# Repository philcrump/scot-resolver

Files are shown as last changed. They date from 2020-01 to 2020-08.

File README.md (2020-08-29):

# scot-resolver

Resolver Interface for the SCOT.

* 22-32V DC Input
* STM32F042K6 Microcontroller @ 48MHz
* MCP2562 CAN 2.0A/B Communication Interface
* AD2S1210 Resolver to Digital Converter
* AD8397 Excitation Driver
* AD8692 Receiver Amplifiers

[**Circuit Board Schematic**](https://github.com/philcrump/scot-resolver/raw/master/scot-resolver-schematic.pdf)

## PCB (CAD Render)

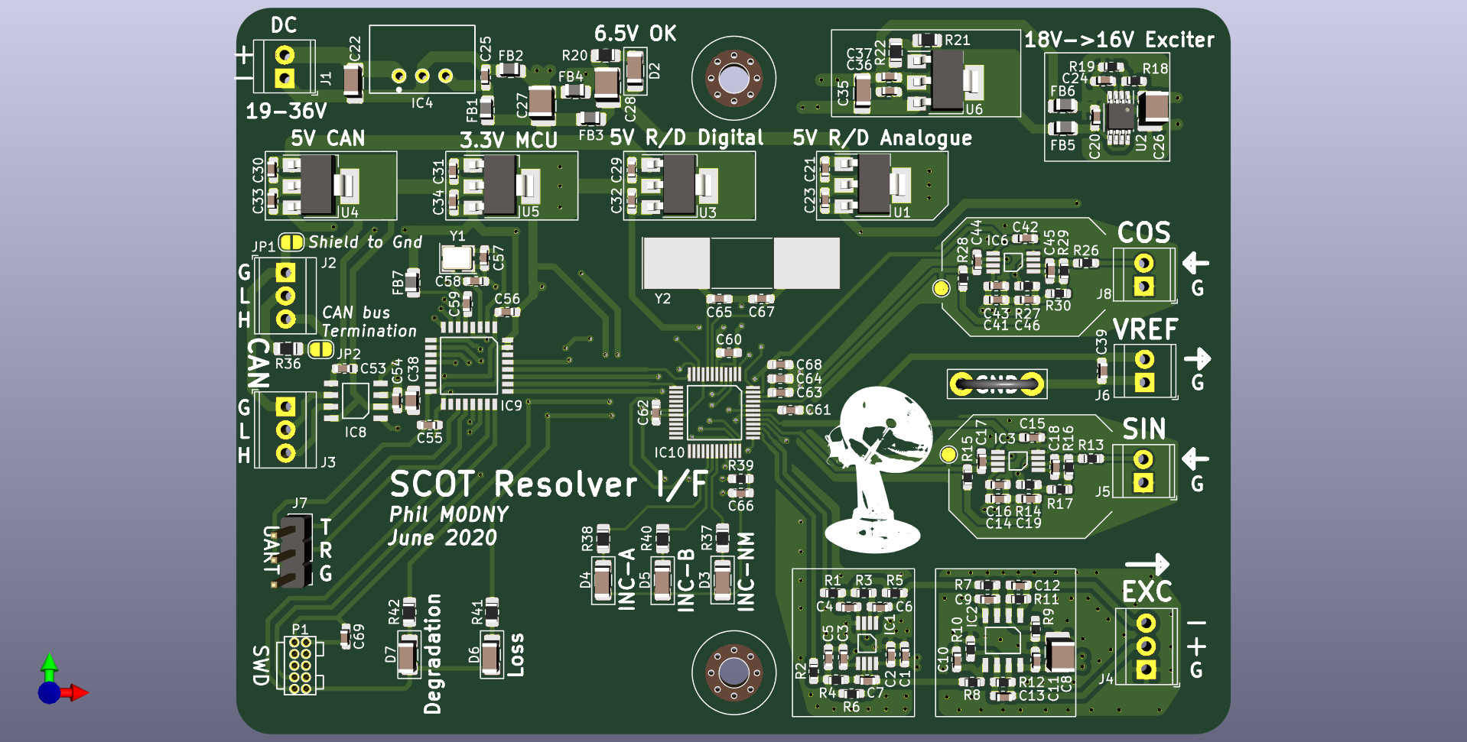
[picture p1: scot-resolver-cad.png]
PCB CAD Render


### June 2020 PCB Errata

* C25 has 0603 pad, C27 & C28 have 1210 pads, all should be 0805 to match the part.
* C26 has 1210 pad, should be 1206.
** Not disastrous, part still fits, with careful placement on 1210 to ensure direct contact with the pads.
* Input Voltage rating is 22-32V, not 19-36V as printed on the PCB (limited by U6-LM317 dropout and thermal).
* Optional Ripple Rejection Capacitor should be fitted across R22 (LM317 regulator)
** 2u2 50V found to prevent oscillation with hostile downstream load (oscillating U2-LT1763)
* C24 U2-LT1763 Bypass Capacitor is incorrectly placed, causes self-oscillation, and should not be populated.
** Attempt to wire this across to Vout instead as recommended also caused output oscillation when under load (25mA).
* U6-LM317 regulator gets hot, within limits but would benefit from more heatsinking / different package.

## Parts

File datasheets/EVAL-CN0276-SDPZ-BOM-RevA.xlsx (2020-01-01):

Title: | CN0276 Bill of Materials
Rev: | 0
Date: | 07/10/2013
Quantity | Reference Designator(s) | Value | Package | Manufacturer | Manufacturer Part Number | Nashua Part Number
2 | C1-2 | 33p | 2012 | KEMET | C0805C330J5GACTU | 7000831
4 | C3-4 C16-17 | 3.9n | 2012 | KOA | NPO0805HTTD3R9J | 7000222
4 | C5-6 C12-13 | 120p | 2012 | muRata | GRM2165C2A121JA01 | .
4 | C7-8 C14-15 | 680p | 2012 | AVX | 08055A681FAT2A | 7000186
1 | C10 | 10n | 2012 | AVX | 08051C103KAT2A | 7000032
6 | C11 C35 C40 C50 C52 C54 | 10u | 2012 | TDK | C2012X5R1V106M125AC | .
2 | C18 C32 | 470p | 2012 | muRata | GRM2165C2A471JA01 | .
2 | C21 C26 | 2.7n | 2012 | TDK | C2012C0G1H272J060AA | .
16 | C22-24 C30-31 C34 C36-37 C39 C41-42 C44-46 C51 C9 | 100n | 2012 | Yageo | CC0805KRX7R8BB104 | 7000758
1 | C38 | 100u | 7343 | AVX | TAJE107M025RNJ | .
2 | C25 C28 | 470u | 7343 | VISHAY | TR3D477M6R3C0200 | 7001327
2 | C20 C29 | 56p | 2012 | muRata | GRM21A5C2E560JW01D | .
2 | C33 C19 | 2.2n | 2012 | TDK | C2012C0G1H222J085AA | .
6 | C43 C27 C47-49 C53 | 1u | 2012 | AVX | 0805ZC105KAT2A | 7000264
2 | D1-2 |  | 2012 | Lumex | SML-LXT0805GW-TR | 7001182
1 | D3 |  | 2012 | Kingbright | APT2012QBC/D | .
1 | D4 |  | 2012 | Kingbright | APT2012SYCK | .
2 | D5-6 |  | 2012 | Avago | HSMS-C170 | 7001059
1 | J1 |  | FX8-120S-SV | HIROSE | FX8-120S-SV | 6000923
1 | J2 |  | IDC20 | Tyco Electronics | 2-1634688-0 | .
1 | J3 |  | 2510-6PIN | Tyco Electronics | 640456-6 | .
1 | J4 |  | 301-2PIN | Weidmüller | PM 5.08/02/90 | 6001003
1 | L1 | 1k | 2012 | TDK | MMZ2012R102A | .
4 | R1 R11 R24 R33 | 4.7k | 2012 | KOA | RK73B2ATTDD472J | 7000044
8 | R5 R2-3 R25-28 R4 | 27k | 2012 | VISHAY | CRCW080527K0FK | .
5 | R7 R6 R16 R47 R57 | 10k | 2012 | KOA | RK73B2ATTD103J | 7000039
1 | R13 | NP
4 | R14-15 R29 R32 | 2k | 2012 | VISHAY | CRCW08052K00FK | 7001433
4 | R30-31 R17-18 | 1.2k | 2012 | KOA | RK73B2ATTDD122J | 7000249
1 | R19 | 100k | 2012 | VISHAY | CRCW0805100KFK | .
5 | R20 R23 R12 R10 R58 | 0 | 2012 | Panasonic | ERJ-6GEY0R00V | 7000228
4 | R8-9 R21-22 | 22k | 2012 | KOA | RK73B2ATTDD223J | 7000095
6 | R34-39 | 1k | 2012 | Yageo | RC0805JR-071KL | 7000554
2 | R40 R56 | 3.3k | 2012 | VISHAY | CRCW08053K30FK | .
2 | R41 R54 | 750 | 2012 | KOA | RK73B2ATTDD751J | 7000162
2 | R43 R52 | 6.2k | 2012 | VISHAY | CRCW08056K20FK | .
2 | R45 R51 | 910 | 2012 | VISHAY | CRCW0805910RFK | .
2 | R46 R48 | 820 | 2012 | VISHAY | CRCW0805820RFK | .
1 | R49 | 390 | 2012 | VISHAY | CRCW0805390RFK | .
4 | R50 R44 R53 R42 | 20k | 2012 | VISHAY | CRCW080520K0FK | .
1 | R55 | 1.6k | 2012 | VISHAY | CRCW08051K60FK | .
1 | U1 |  | SOIC-8 | Microchip | 24LC32A-I/SN | 1000614
2 | U2 U5 |  | SOIC-14 | Analog Devices, Inc. | AD8694ARZ | .
1 | U3 |  | TSSOP-16 | Analog Devices, Inc. | ADG1611BRUZ | .
1 | U4 |  | LQFP-48 | Analog Devices, Inc. | AD2S1210BSTZ | .
1 | U6 |  | SOIC-8 | Analog Devices, Inc. | AD8692ARZ | .
1 | U7 |  | SOIC-EP-8 | Analog Devices, Inc. | AD8397ARDZ | 30-025792-01
1 | U8 |  | TSSOP-16 | Analog Devices, Inc. | ADG1612BRUZ | .
1 | U9 |  | SOT-23-3 | Analog Devices, Inc. | ADM6328-22ARTZ-R7 | .
1 | U10 |  | SOIC-EP-8 | Analog Devices, Inc. | ADP7104ARDZ-5.0-R7 | 30-026221-01
1 | U11 |  | SOIC-EP-8 | Analog Devices, Inc. | ADP7104ARDZ-3.3-R7 | 30-026222-01
1 | U12 |  | SOT-23-3 | VISHAY | SI2343CDS | 1000351
1 | Y1 | 8.192M | HCM49 | TXC | 9C-8.192MAAJ-T | .

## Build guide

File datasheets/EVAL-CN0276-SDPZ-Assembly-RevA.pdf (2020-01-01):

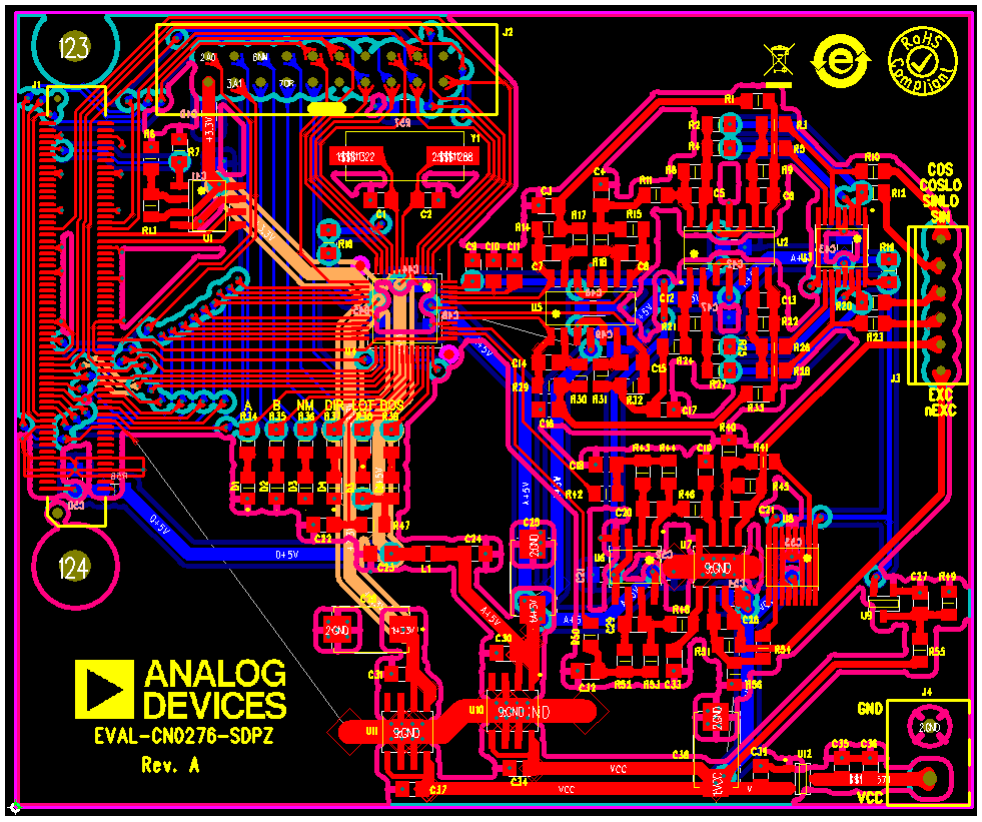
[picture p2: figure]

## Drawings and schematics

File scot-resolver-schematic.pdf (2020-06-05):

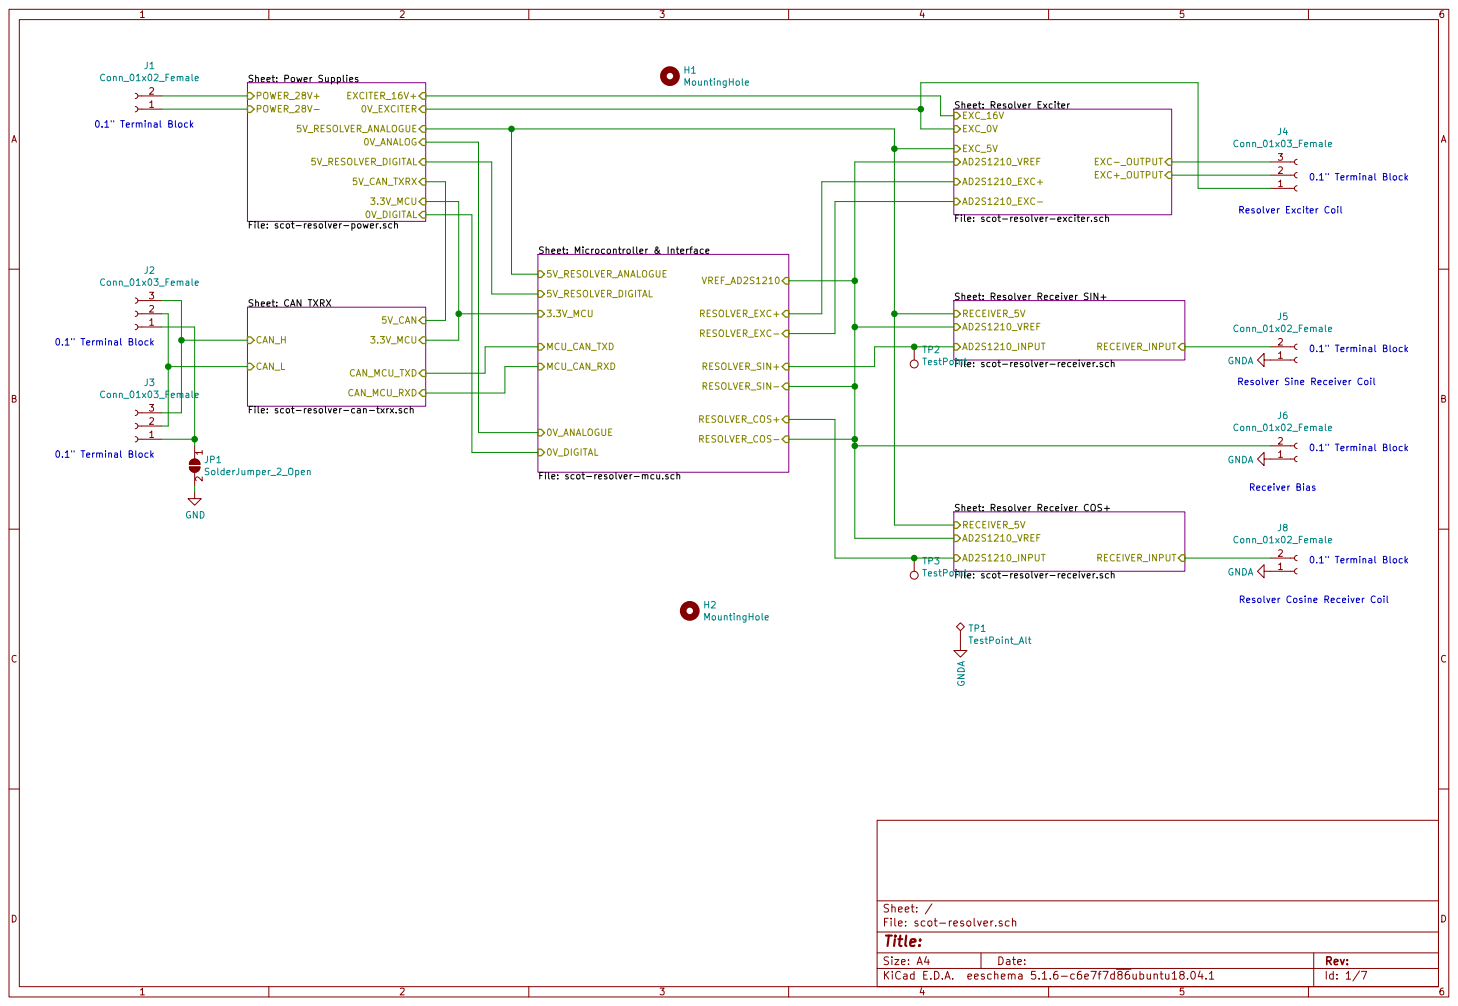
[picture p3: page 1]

Sheet: Microcontroller & Interface File: scot-resolver-mcu.sch MCU_CAN_TXD MCU_CAN_RXD

File: scot-resolver-can-txrx.sch CAN_L CAN_H

Id: 1/7 Title: File: scot-resolver.sch Sheet: /

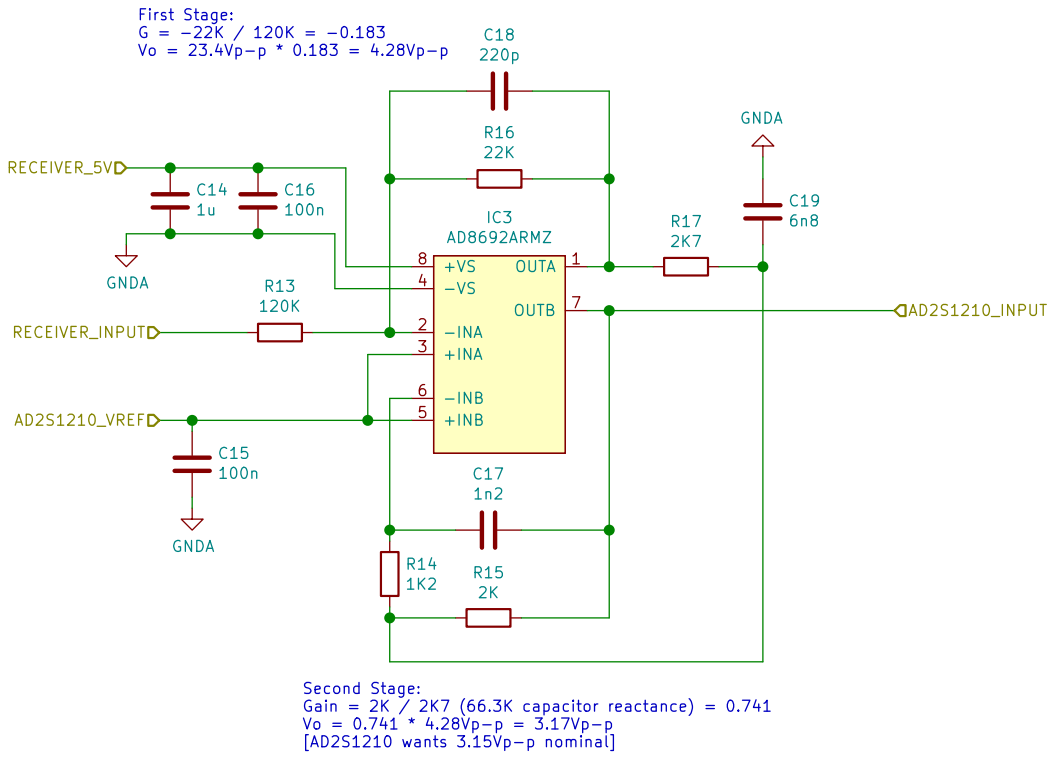
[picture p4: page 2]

Id: 2/7 Title: File: scot-resolver-receiver.sch Sheet: /Resolver Receiver SIN+/

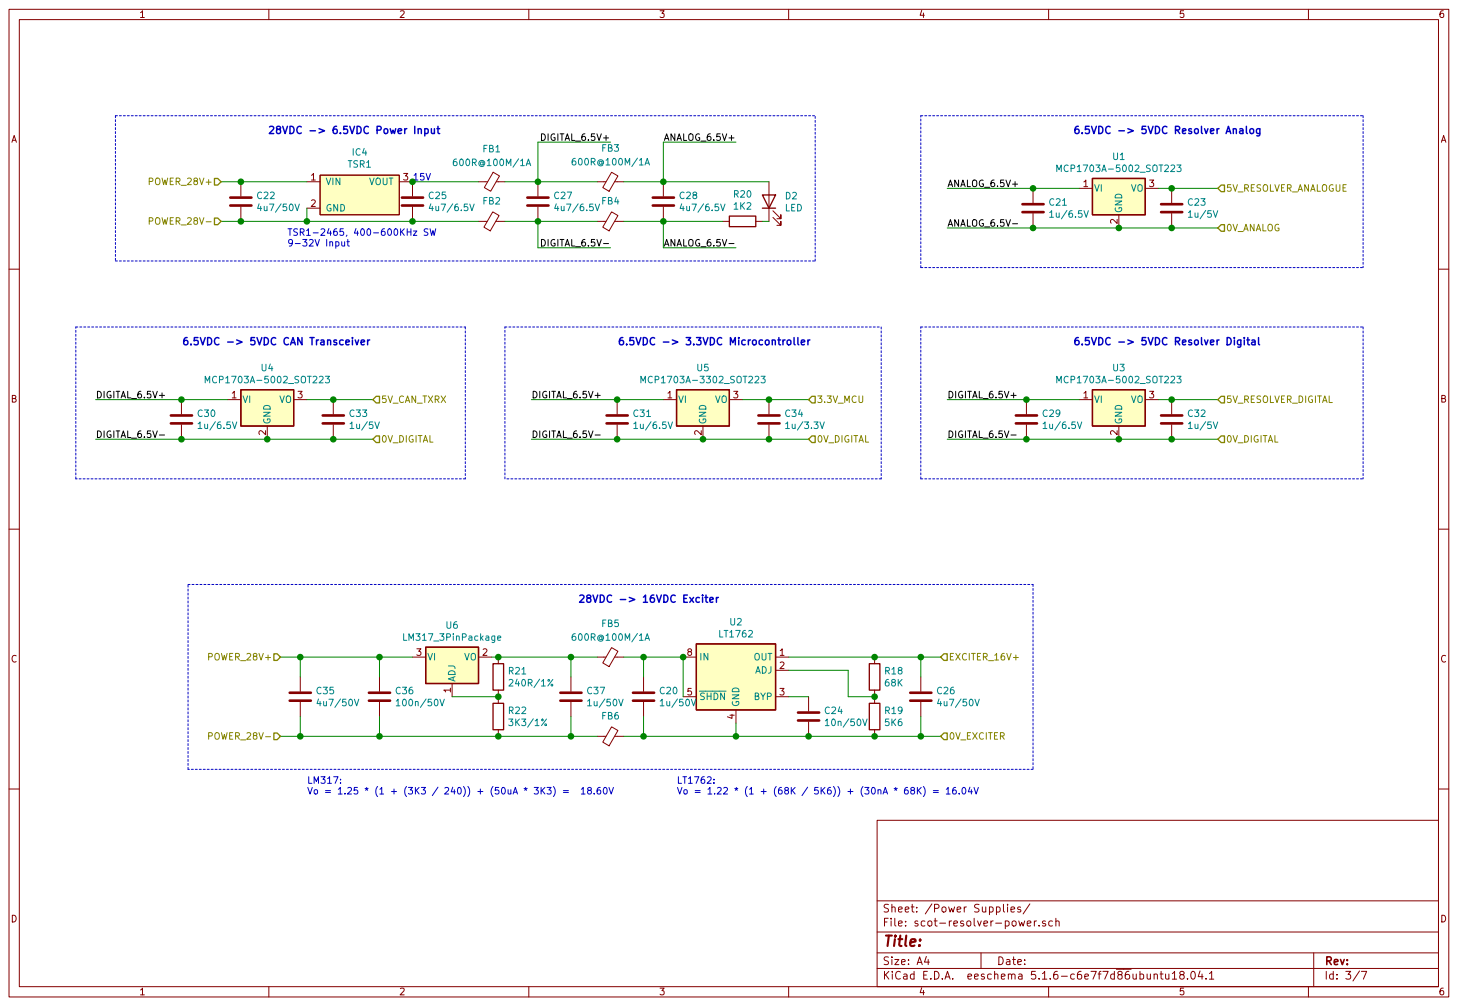
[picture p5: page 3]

Sheet: /Power Supplies/
File: scot-resolver-power.sch
Id: 3/7 Title:

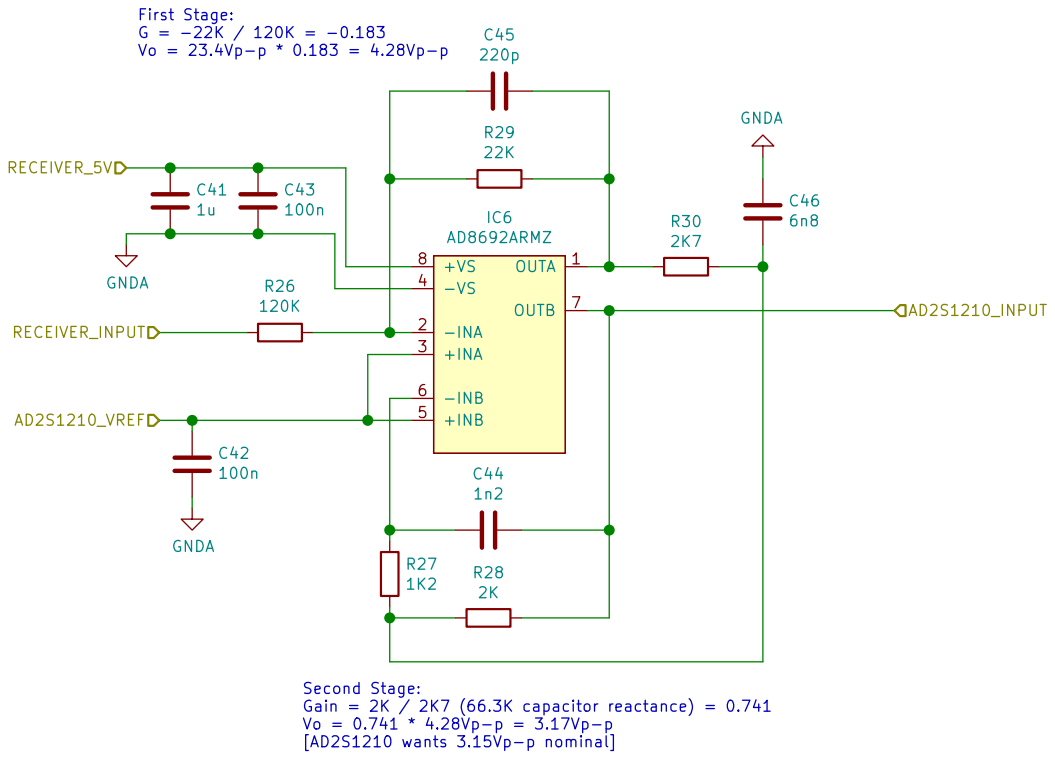
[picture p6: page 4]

Id: 4/7 Title: File: scot-resolver-receiver.sch Sheet: /Resolver Receiver COS+/

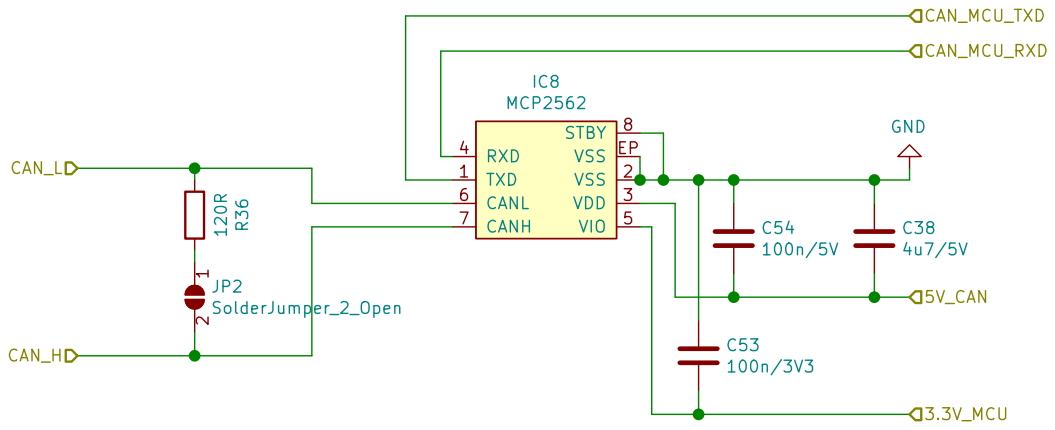
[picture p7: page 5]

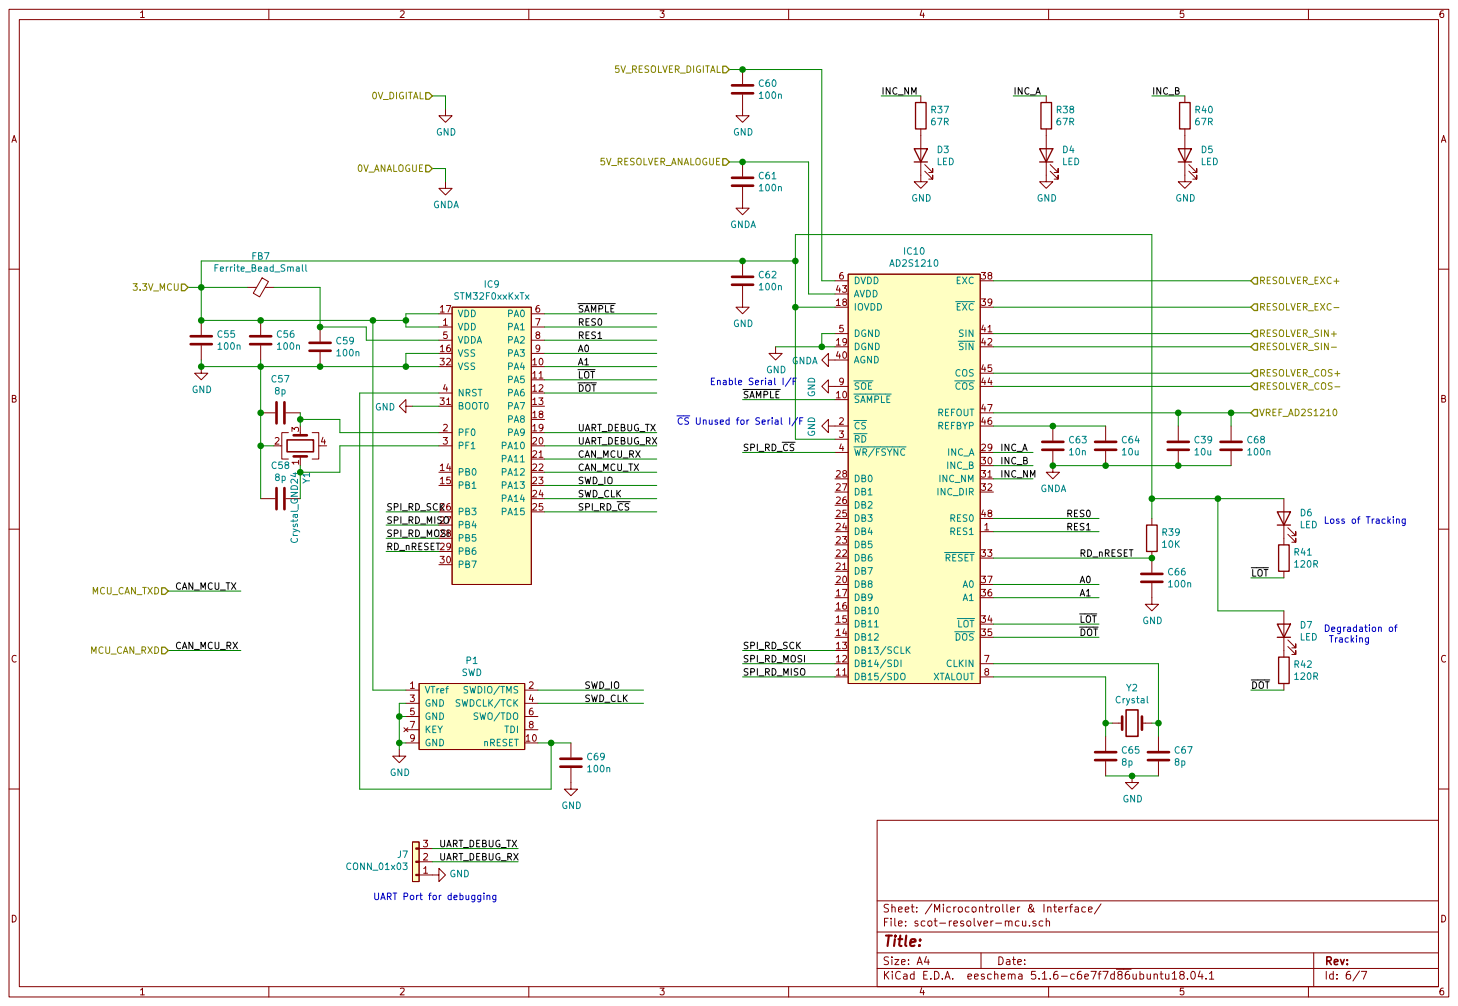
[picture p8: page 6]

Id: 6/7 Title: File: scot-resolver-mcu.sch Sheet: /Microcontroller & Interface/ GND

UART Port for debugging

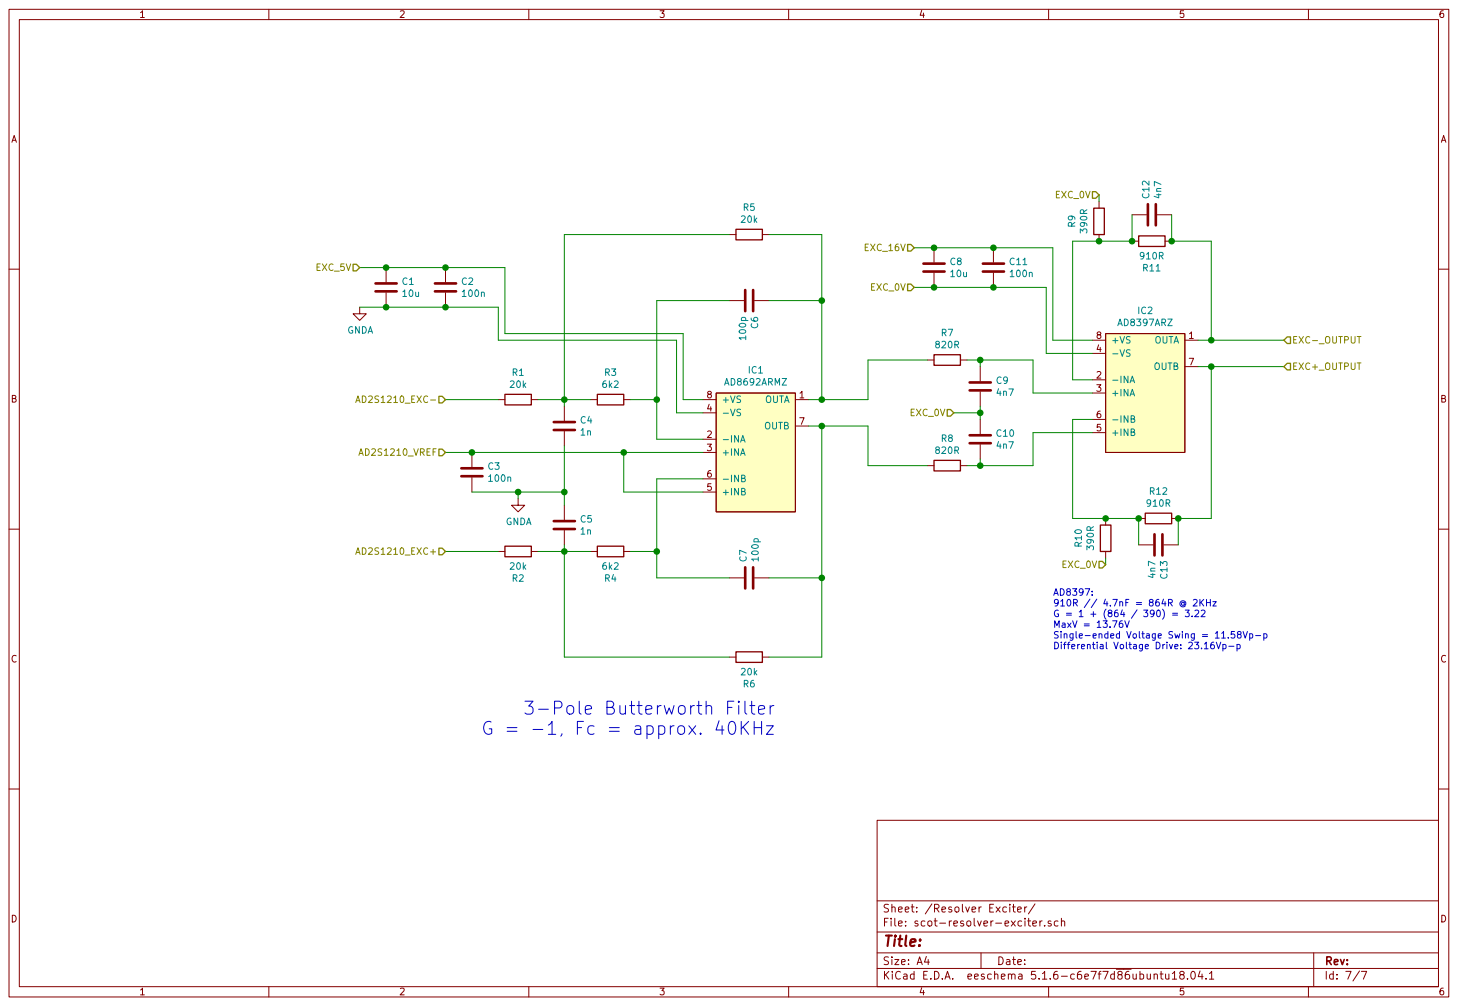
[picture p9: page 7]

Single-ended Voltage Swing = 11.58Vp-p
Differential Voltage Drive: 23.16Vp-p

Id: 7/7 Title: File: scot-resolver-exciter.sch Sheet: /Resolver Exciter/

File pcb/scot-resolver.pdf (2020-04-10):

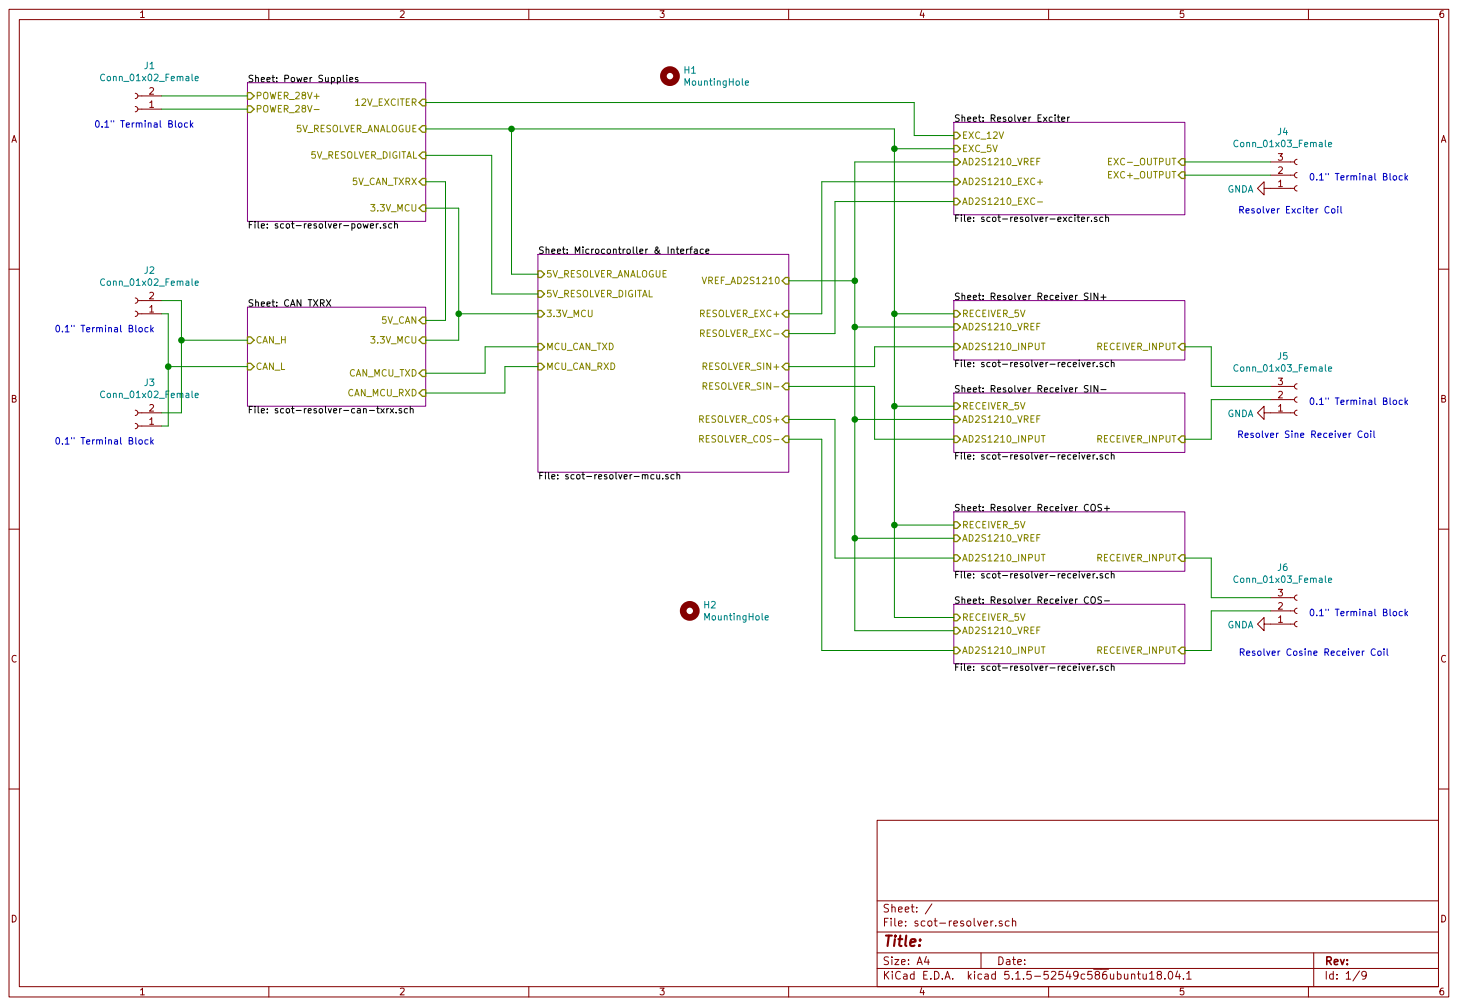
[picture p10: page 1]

File: scot-resolver-power.sch

Sheet: Microcontroller & Interface File: scot-resolver-mcu.sch MCU_CAN_TXD MCU_CAN_RXD

File: scot-resolver-can-txrx.sch CAN_L CAN_H

Id: 1/9 Title: File: scot-resolver.sch Sheet: /

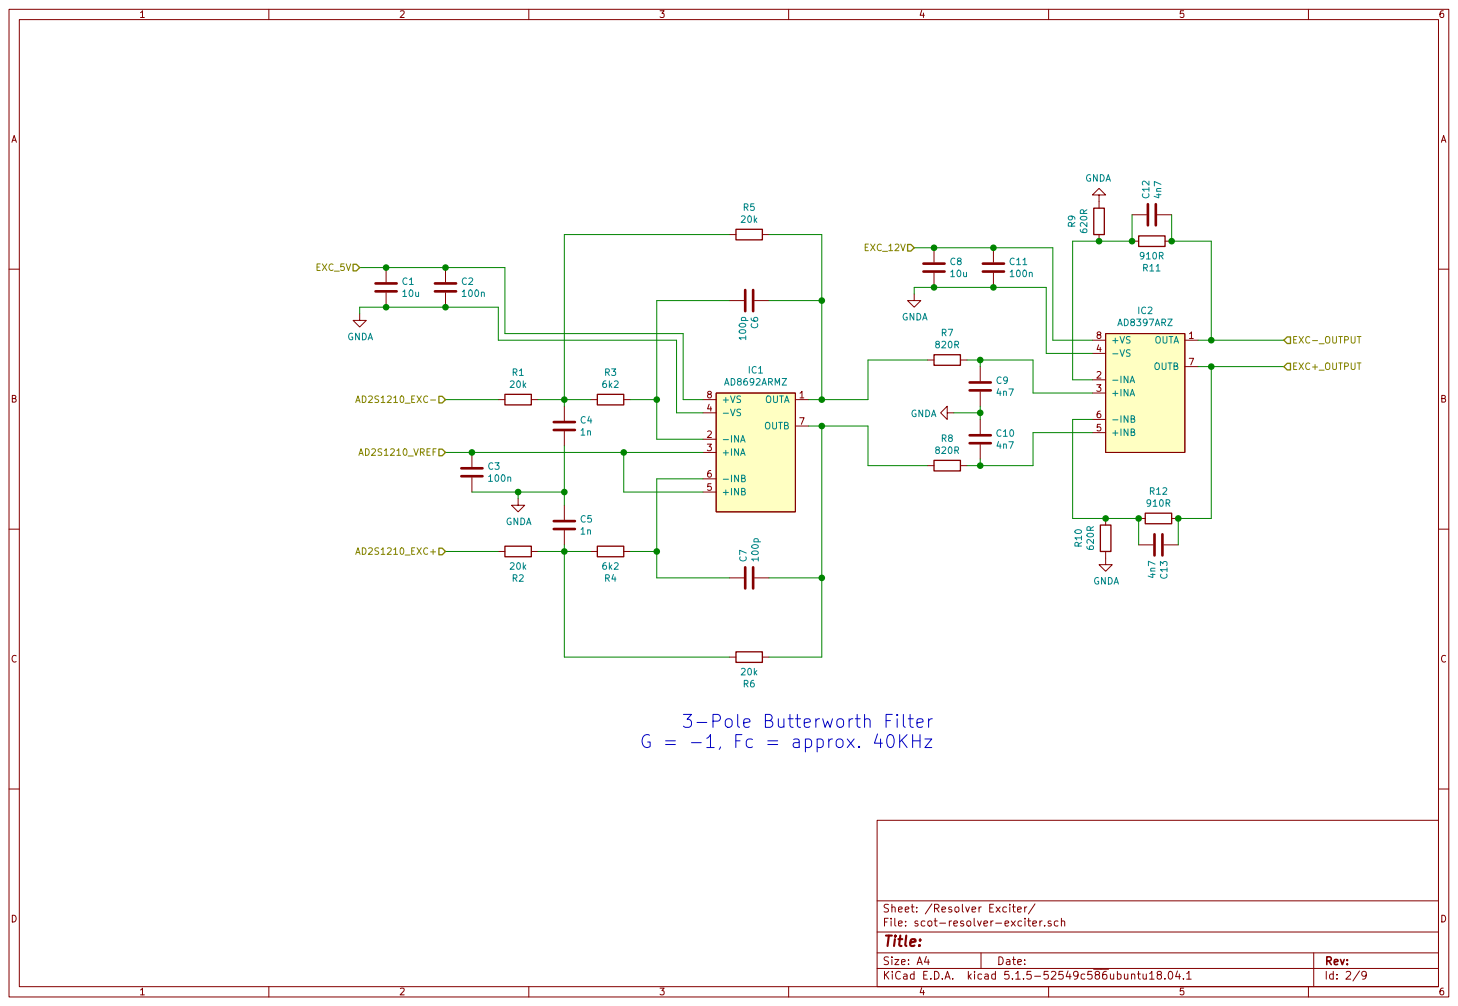
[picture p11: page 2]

Id: 2/9 Title: File: scot-resolver-exciter.sch Sheet: /Resolver Exciter/

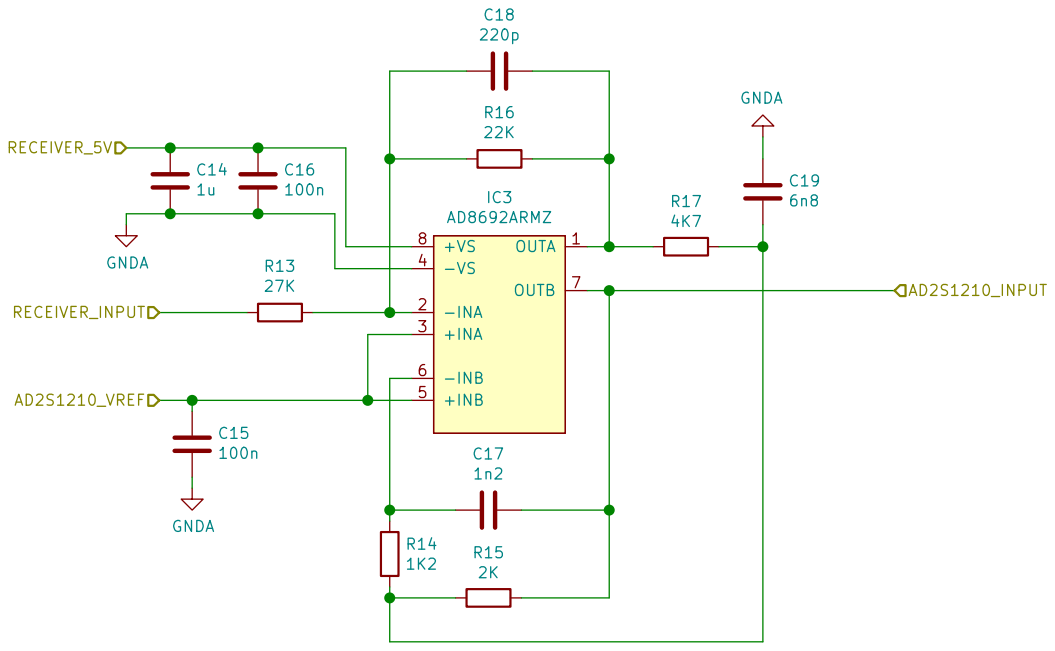
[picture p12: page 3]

Id: 3/9 Title: File: scot-resolver-receiver.sch Sheet: /Resolver Receiver SIN+/

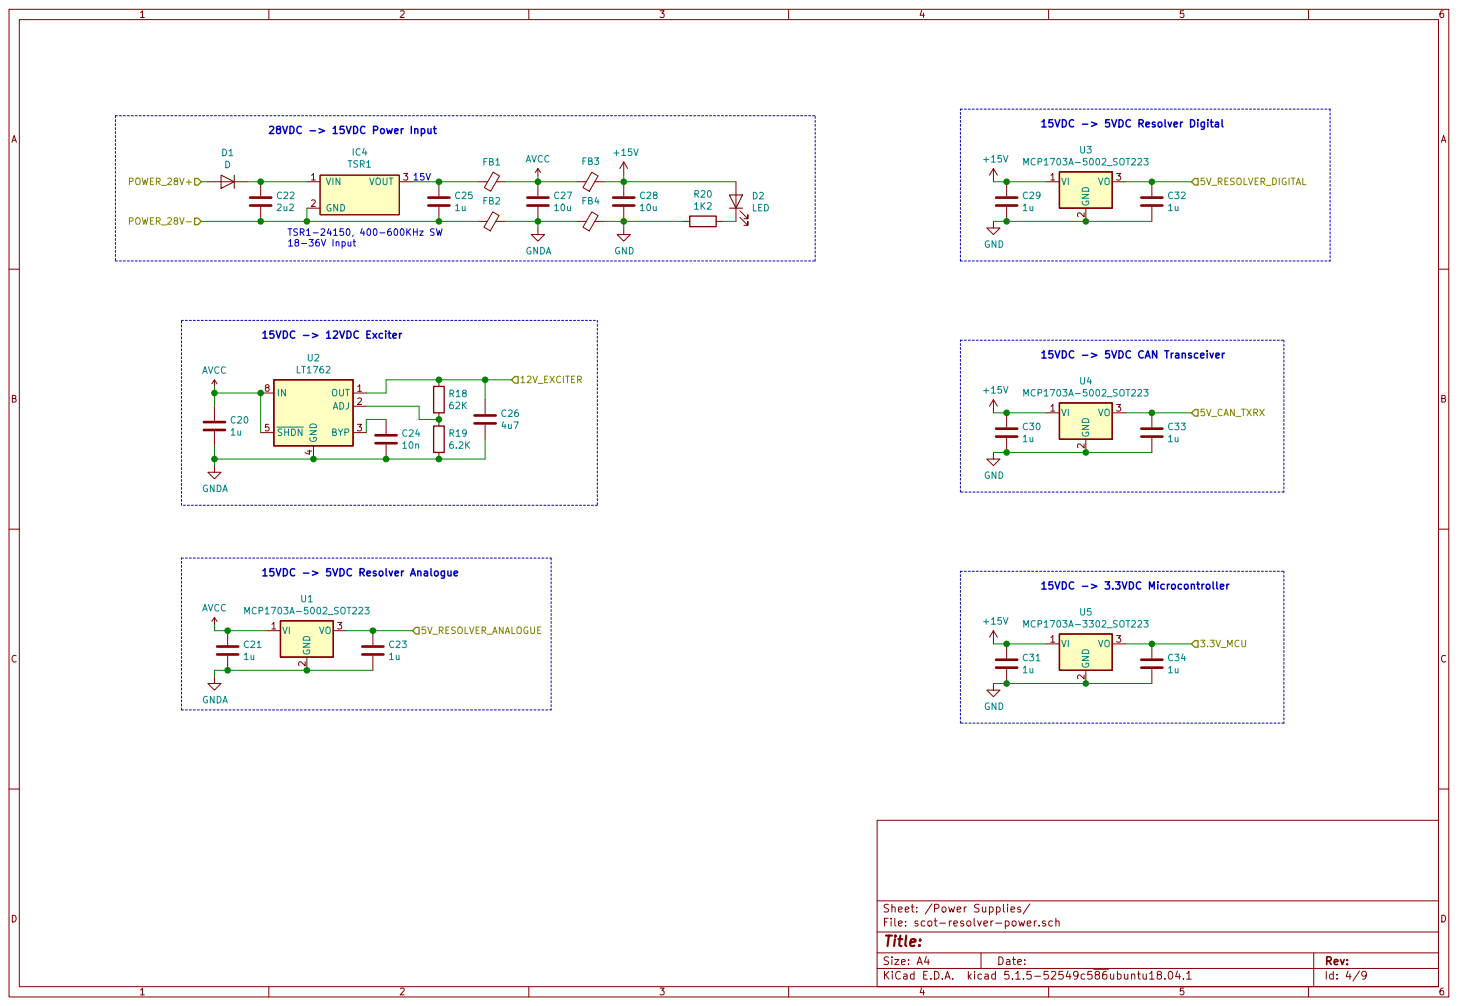
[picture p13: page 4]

15VDC -> 3.3VDC Microcontroller 15VDC -> 5VDC CAN Transceiver 28VDC -> 15VDC Power Input

Sheet: /Power Supplies/
File: scot-resolver-power.sch
Id: 4/9 Title:

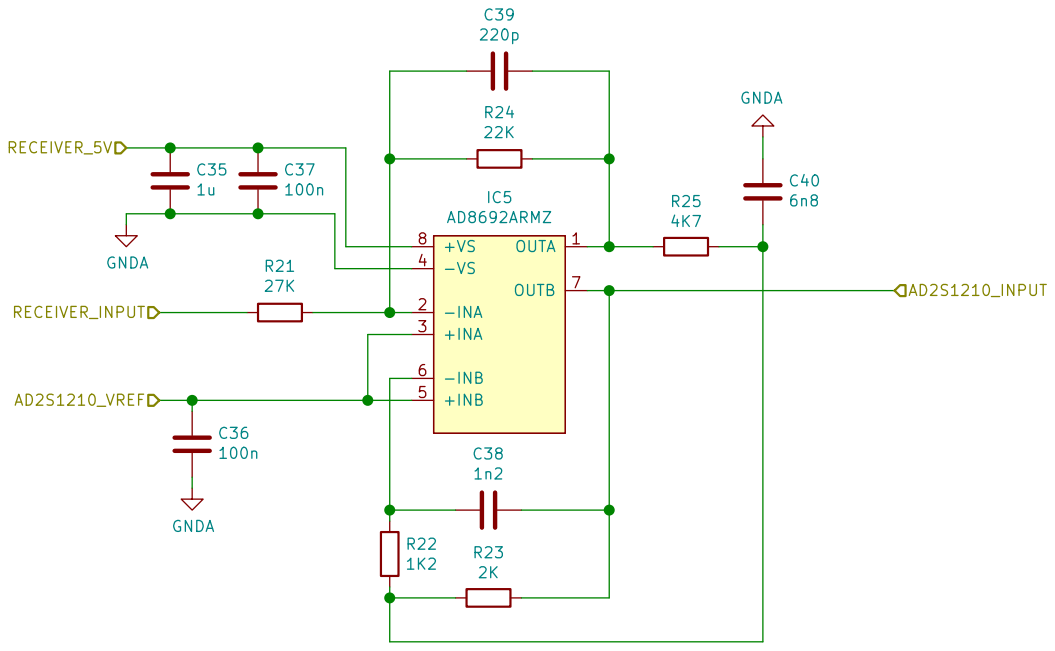
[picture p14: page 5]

Id: 5/9 Title: File: scot-resolver-receiver.sch Sheet: /Resolver Receiver SIN-/


Id: 6/9 Title: File: scot-resolver-receiver.sch Sheet: /Resolver Receiver COS+/


Id: 7/9 Title: File: scot-resolver-receiver.sch Sheet: /Resolver Receiver COS-/



Tracking Enable Serial I/F CS Unused for Serial I/F

UART Port for debugging

Id: 9/9 Title: File: scot-resolver-mcu.sch Sheet: /Microcontroller & Interface/

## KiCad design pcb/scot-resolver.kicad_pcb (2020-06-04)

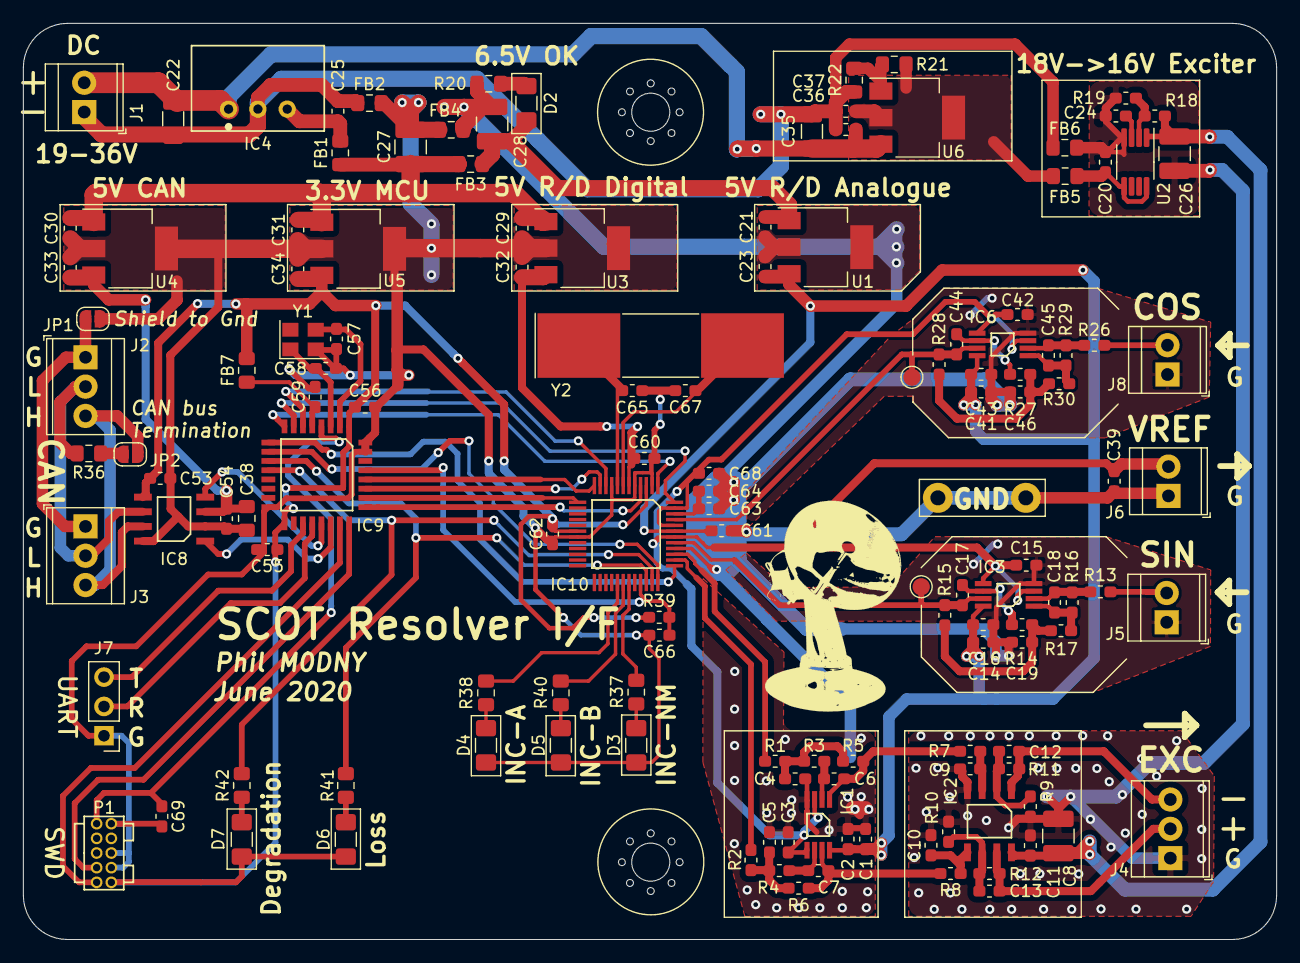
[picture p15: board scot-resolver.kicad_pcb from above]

Board: 2 copper layers, 108.6 x 79.4 mm, 141 parts (0 on the bottom side), 83 nets.

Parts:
C1, C39, C64: 10u; C_0603_1608Metric_Pad1.05x0.95mm_HandSolder
C2, C3, C11, C15, C16, C42, C43, C55, C56, C59, C60, C61, C62, C66, C68, C69: 100n; C_0603_1608Metric_Pad1.05x0.95mm_HandSolder
C4, C5: 1n; C_0603_1608Metric_Pad1.05x0.95mm_HandSolder
C6, C7: 100p; C_0603_1608Metric_Pad1.05x0.95mm_HandSolder
C8: 10u; C_1210_3225Metric_Pad1.42x2.65mm_HandSolder
C9, C10, C12, C13: 4n7; C_0603_1608Metric_Pad1.05x0.95mm_HandSolder
C14, C20, C41: 1u; C_0603_1608Metric_Pad1.05x0.95mm_HandSolder
C17, C44: 1n2; C_0603_1608Metric_Pad1.05x0.95mm_HandSolder
C18, C45: 220p; C_0603_1608Metric_Pad1.05x0.95mm_HandSolder
C19, C46: 6n8; C_0603_1608Metric_Pad1.05x0.95mm_HandSolder
C21, C29, C30, C31: 1u/6.5V; C_0603_1608Metric_Pad1.05x0.95mm_HandSolder
C22, C35: 4u7/50V; C_1206_3216Metric_Pad1.42x1.75mm_HandSolder
C23, C32, C33: 1u/5V; C_0603_1608Metric_Pad1.05x0.95mm_HandSolder
C24: 10n/50V; C_0603_1608Metric_Pad1.05x0.95mm_HandSolder
C25: 4u7/6.5V; C_0603_1608Metric_Pad1.05x0.95mm_HandSolder
C26: 4u7/50V; C_1210_3225Metric_Pad1.42x2.65mm_HandSolder
C27, C28: 4u7/6.5V; C_1210_3225Metric_Pad1.42x2.65mm_HandSolder
C34: 1u/3.3V; C_0603_1608Metric_Pad1.05x0.95mm_HandSolder
C36: 100n/50V; C_0603_1608Metric_Pad1.05x0.95mm_HandSolder
C37: 4u7/50V; C_0603_1608Metric_Pad1.05x0.95mm_HandSolder
C38: 4u7/5V; C_0805_2012Metric_Pad1.15x1.40mm_HandSolder
C53: 100n/3V3; C_0603_1608Metric_Pad1.05x0.95mm_HandSolder
C54: 100n/5V; C_0603_1608Metric_Pad1.05x0.95mm_HandSolder
C57, C58: 8p; C_0603_1608Metric_Pad1.05x0.95mm_HandSolder
C63: 10n; C_0603_1608Metric_Pad1.05x0.95mm_HandSolder
C65, C67: 18p; C_0603_1608Metric_Pad1.05x0.95mm_HandSolder
D2, D3, D4, D5, D6, D7: LED; C_1206_3216Metric_Pad1.42x1.75mm_HandSolder
FB1, FB2, FB3, FB4, FB5, FB6: 600R@100M/1A; L_0805_2012Metric_Pad1.15x1.40mm_HandSolder
FB7: Ferrite_Bead_Small; L_0805_2012Metric_Pad1.15x1.40mm_HandSolder
H1, H2: MountingHole; M3_MOUNT
IC1, IC3, IC6: AD8692ARMZ; MSOP-8
IC2: AD8397ARZ; SOIC-8
IC4: TSR1
IC8: MCP2562; SOIC-8
IC9: STM32F0xxKxTx; LQFP-32
IC10: AD2S1210; LQFP-48
J1, J5, J6, J8: Conn_01x02_Female; TerminalBlock_TE_282834-2_1x02_P2.54mm_Horizontal
J2, J3, J4: Conn_01x03_Female; TerminalBlock_TE_282834-3_1x03_P2.54mm_Horizontal
J7: CONN_01x03; PinHeader_1x03_P2.54mm_Vertical
JP1, JP2: SolderJumper_2_Open; SolderJumper-2_P1.3mm_Open_RoundedPad1.0x1.5mm
P1: SWD; FTSH-105-01-F-D-K
R1, R2, R5, R6: 20k; R_0603_1608Metric_Pad1.05x0.95mm_HandSolder
R3, R4: 6k2; R_0603_1608Metric_Pad1.05x0.95mm_HandSolder
R7, R8: 820R; R_0603_1608Metric_Pad1.05x0.95mm_HandSolder
R9, R10: 390R; R_0603_1608Metric_Pad1.05x0.95mm_HandSolder
R11, R12: 910R; R_0603_1608Metric_Pad1.05x0.95mm_HandSolder
R13, R26: 120K; R_0603_1608Metric_Pad1.05x0.95mm_HandSolder
R14, R27: 1K2; R_0603_1608Metric_Pad1.05x0.95mm_HandSolder
R15, R28: 2K; R_0603_1608Metric_Pad1.05x0.95mm_HandSolder
R16, R29: 22K; R_0603_1608Metric_Pad1.05x0.95mm_HandSolder
R17, R30: 2K7; R_0603_1608Metric_Pad1.05x0.95mm_HandSolder
R18: 68K; R_0603_1608Metric_Pad1.05x0.95mm_HandSolder
R19: 5K6; R_0603_1608Metric_Pad1.05x0.95mm_HandSolder
R20: 1K2; R_0805_2012Metric_Pad1.15x1.40mm_HandSolder
R21: 240R/1%; R_0805_2012Metric_Pad1.15x1.40mm_HandSolder
R22: 3K2/1%; R_0805_2012Metric_Pad1.15x1.40mm_HandSolder
R36, R41, R42: 120R; R_0805_2012Metric_Pad1.15x1.40mm_HandSolder
R37, R38, R40: 67R; R_0805_2012Metric_Pad1.15x1.40mm_HandSolder
R39: 10K; R_0603_1608Metric_Pad1.05x0.95mm_HandSolder
TP1: TestPoint_Alt; TestPoint_Bridge_Pitch7.62mm_Drill1.3mm
TP3: TestPoint; TestPoint_Pad_D1.5mm
TPe: TestPoint; TestPoint_Pad_D1.5mm
U1, U3, U4: MCP1703A-5002_SOT223; SOT-223-3_TabPin2
U2: LT1762; MSOP-8_3x3mm_P0.65mm
U5: MCP1703A-3302_SOT223; SOT-223-3_TabPin2
U6: LM317_3PinPackage; SOT-223-3_TabPin2
Y1: Crystal_GND24; Crystal_SMD_Abracon_ABM8G-4Pin_3.2x2.5mm
Y2: Crystal; Crystal_SMD_SeikoEpson_MA505-2Pin_12.7x5.1mm_HandSoldering

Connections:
/CAN TXRX/3.3V_MCU: C34.1, C53.2, C55.1, C56.1, C62.1, D6.2, D7.2, FB7.2, IC8.5, IC9.1, IC9.17, IC10.3, IC10.18, P1.1, R39.1, U5.3
/CAN TXRX/5V_CAN: C33.1, C38.2, C54.2, IC8.3, U4.3
/CAN TXRX/CAN_H: IC8.7, J2.3, J3.3, JP2.2
/CAN TXRX/CAN_L: IC8.6, J2.2, J3.2, R36.2
/CAN TXRX/CAN_MCU_RXD: IC8.4, IC9.21
/CAN TXRX/CAN_MCU_TXD: IC8.1, IC9.22
/Microcontroller & Interface/5V_RESOLVER_ANALOGUE: C1.1, C2.1, C14.2, C16.2, C23.1, C41.2, C43.2, C61.1, IC1.8, IC3.8, IC6.8, IC10.43, U1.3
/Microcontroller & Interface/5V_RESOLVER_DIGITAL: C32.1, C60.1, IC10.6, U3.3
/Microcontroller & Interface/A0: IC9.9, IC10.37
/Microcontroller & Interface/A1: IC9.10, IC10.36
/Microcontroller & Interface/INC_A: IC10.29, R38.1
/Microcontroller & Interface/INC_B: IC10.30, R40.1
/Microcontroller & Interface/INC_NM: IC10.31, R37.1
/Microcontroller & Interface/RD_nRESET: C66.1, IC9.29, IC10.33, R39.2
/Microcontroller & Interface/RES0: IC9.7, IC10.48
/Microcontroller & Interface/RES1: IC9.8, IC10.1
/Microcontroller & Interface/SPI_RD_MISO: IC9.27, IC10.11
/Microcontroller & Interface/SPI_RD_MOSI: IC9.28, IC10.12
/Microcontroller & Interface/SPI_RD_SCK: IC9.26, IC10.13
/Microcontroller & Interface/SPI_RD_~CS: IC9.25, IC10.4
/Microcontroller & Interface/SWD_CLK: IC9.24, P1.4
/Microcontroller & Interface/SWD_IO: IC9.23, P1.2
/Microcontroller & Interface/UART_DEBUG_RX: IC9.20, J7.2
/Microcontroller & Interface/UART_DEBUG_TX: IC9.19, J7.3
/Microcontroller & Interface/~DOT: IC9.12, IC10.35, R42.2
/Microcontroller & Interface/~LOT: IC9.11, IC10.34, R41.2
/Microcontroller & Interface/~SAMPLE: IC9.6, IC10.10
/Power Supplies/0V_EXCITER: C8.2, C9.2, C10.1, C11.2, C20.2, C24.2, C26.2, FB6.2, IC2.4, J4.1, R9.1, R10.2, R19.2, U2.4
/Power Supplies/ANALOG_6.5V+: C21.1, C28.1, D2.2, FB3.2, U1.1
/Power Supplies/DIGITAL_6.5V+: C27.1, C29.1, C30.1, C31.1, FB1.1, FB3.1, U3.1, U4.1, U5.1
/Power Supplies/EXCITER_16V+: C8.1, C11.1, C26.1, IC2.8, R18.1, U2.1
/Power Supplies/POWER_28V+: C22.1, C35.1, C36.1, IC4.1, J1.2, U6.3
/Power Supplies/POWER_28V-: C22.2, C25.2, C35.2, C36.2, C37.2, FB2.1, FB6.1, IC4.2, J1.1, R22.2
/Resolver Exciter/AD2S1210_EXC+: IC10.38, R2.1
/Resolver Exciter/AD2S1210_EXC-: IC10.39, R1.2
/Resolver Exciter/AD2S1210_VREF: C3.1, C15.2, C39.1, C42.2, C68.1, IC1.3, IC1.5, IC3.3, IC3.5, IC6.3, IC6.5, IC10.42, IC10.44, IC10.47, J6.2
/Resolver Exciter/EXC+_OUTPUT: C13.1, IC2.7, J4.2, R12.1
/Resolver Exciter/EXC-_OUTPUT: C12.2, IC2.1, J4.3, R11.2
/Resolver Receiver COS+/AD2S1210_INPUT: C44.2, IC6.7, IC10.45, R28.1, TP3.1
/Resolver Receiver COS+/RECEIVER_INPUT: J8.2, R26.1
/Resolver Receiver SIN+/AD2S1210_INPUT: C17.2, IC3.7, IC10.41, R15.1, TPe.1
/Resolver Receiver SIN+/RECEIVER_INPUT: J5.2, R13.1
GND: C27.2, C29.2, C30.2, C31.2, C32.2, C33.2, C34.2, C38.1, C53.1, C54.1, C55.2, C56.2, C57.1, C58.2, C59.2, C60.2, C62.2, C65.2, C66.2, C67.2, C69.2, D3.1, D4.1, D5.1, FB2.2, FB4.1, IC8.2, IC8.8, IC9.16, IC9.31, IC9.32, IC10.2, IC10.5, IC10.9, IC10.19, J7.1, JP1.2, P1.3, P1.5, P1.9, U3.2, U4.2, U5.2, Y1.2
GNDA: C1.2, C2.2, C3.2, C4.2, C5.1, C14.1, C15.1, C16.1, C19.2, C21.2, C23.2, C28.2, C39.2, C41.1, C42.1, C43.1, C46.2, C61.2, C63.2, C64.2, C68.2, FB4.2, IC1.4, IC3.4, IC6.4, IC10.40, J5.1, J6.1, J8.1, R20.2, TP1.1, U1.2
unnamed: C4.1, R1.1, R3.2, R5.2
unnamed: C5.2, R2.2, R4.1, R6.1
unnamed: C6.1, IC1.1, R5.1, R7.2
unnamed: C6.2, IC1.2, R3.1
unnamed: C7.1, IC1.6, R4.2
unnamed: C7.2, IC1.7, R6.2, R8.2
unnamed: C9.1, IC2.3, R7.1
unnamed: C10.2, IC2.5, R8.1
unnamed: C12.1, IC2.2, R9.2, R11.1
unnamed: C13.2, IC2.6, R10.1, R12.2
unnamed: C17.1, IC3.6, R14.1
unnamed: C18.1, IC3.2, R13.2, R16.1
unnamed: C18.2, IC3.1, R16.2, R17.2
unnamed: C19.1, R14.2, R15.2, R17.1
unnamed: C20.1, FB5.2, U2.5, U2.8
unnamed: C24.1, U2.3
unnamed: C25.1, FB1.2, IC4.3
unnamed: C37.1, FB5.1, R21.1, U6.2
unnamed: C44.1, IC6.6, R27.1
unnamed: C45.1, IC6.2, R26.2, R29.1
unnamed: C45.2, IC6.1, R29.2, R30.2
unnamed: C46.1, R27.2, R28.2, R30.1
unnamed: C57.2, IC9.2, Y1.3
unnamed: C58.1, IC9.3, Y1.1
unnamed: C59.1, FB7.1, IC9.5
unnamed: C63.1, C64.1, IC10.46
unnamed: C65.1, IC10.8, Y2.1
unnamed: C67.1, IC10.7, Y2.2
unnamed: C69.1, IC9.4, P1.10
unnamed: D2.1, R20.1
unnamed: D3.2, R37.2
unnamed: D4.2, R38.2
unnamed: D5.2, R40.2
unnamed: D6.1, R41.1
unnamed: D7.1, R42.1
unnamed: J2.1, J3.1, JP1.1
unnamed: JP2.1, R36.1
unnamed: R18.2, R19.1, U2.2
unnamed: R21.2, R22.1, U6.1

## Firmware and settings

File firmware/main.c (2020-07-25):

#include "main.h"

extern char config_device_id_hexstr[25];
extern char config_can_address_prefix_hexstr[5];

static const SerialConfig serial_cfg = {
  115200,
  0,
  0,
  0
};

void sdWriteString(SerialDriver *sdp, const char *string)
{
  uint32_t i;
  for(i = 0; string[i] != '\0'; i++)
  {
    sdPut(sdp, string[i]);
  }
}

THD_WORKING_AREA(ad2s1210_service_wa, 128);
THD_WORKING_AREA(can_rx_service_wa, 128);
THD_WORKING_AREA(watchdog_service_wa, 128);

int main(void)
{
  halInit();
  chSysInit();

  watchdog_init();
  chThdCreateStatic(watchdog_service_wa, sizeof(watchdog_service_wa), HIGHPRIO, watchdog_service_thread, NULL);

  config_init();

  /* Start Debug Console (115200 8n1) */
  sdStart(&SD1, &serial_cfg);

  sdWriteString(&SD1, "SCOT Resolver Interface - Phil Crump M0DNY\r\n");
  sdWriteString(&SD1, " - Version: " GITVERSION "\r\n");
  sdWriteString(&SD1, " - STM32 ID: ");
  sdWriteString(&SD1, config_device_id_hexstr);
  sdWriteString(&SD1, "\r\n");
  sdWriteString(&SD1, " - CAN ADDRESS: ");
  sdWriteString(&SD1, config_can_address_prefix_hexstr);
  sdWriteString(&SD1, "\r\n");

  chThdCreateStatic(can_rx_service_wa, sizeof(can_rx_service_wa), NORMALPRIO, can_rx_service_thread, NULL);
  chThdCreateStatic(ad2s1210_service_wa, sizeof(ad2s1210_service_wa), NORMALPRIO, ad2s1210_service_thread, NULL);

  systime_t start, end;
  while(true)
  {
    can_send_sysinfo(GITVERSION_X32, system_mcutemperature());

    /* Set timer for 10s */
    start = chVTGetSystemTime();
    end = chTimeAddX(start, TIME_S2I(10));
    while (chVTIsSystemTimeWithin(start, end))
    {
      /* Feed watchdog, sleep for 100ms, repeat */
      watchdog_feed(WATCHDOG_DOG_MAIN);
      chThdSleepMilliseconds(100);
    }
  }
}

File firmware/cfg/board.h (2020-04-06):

/*
    ChibiOS - Copyright (C) 2006..2018 Giovanni Di Sirio

    Licensed under the Apache License, Version 2.0 (the "License");
    you may not use this file except in compliance with the License.
    You may obtain a copy of the License at

        http://www.apache.org/licenses/LICENSE-2.0

    Unless required by applicable law or agreed to in writing, software
    distributed under the License is distributed on an "AS IS" BASIS,
    WITHOUT WARRANTIES OR CONDITIONS OF ANY KIND, either express or implied.
    See the License for the specific language governing permissions and
    limitations under the License.
*/

#ifndef BOARD_H
#define BOARD_H

/*===========================================================================*/
/* Driver constants.                                                         */
/*===========================================================================*/

/*
 * Setup for Phil Crump's SCOT Resolver Interface board.
 */

/*
 * Board identifier.
 */
#define BOARD_SCOT_RESOLVER_rFeb2020
#define BOARD_NAME                  "SCOT Resolver Interface - Feb 2020"

/*
 * Board oscillators-related settings.
 * NOTE: LSE not fitted.
 * NOTE: HSE 8MHz 10ppm XTAL fitted.
 */
#if !defined(STM32_LSECLK)
#define STM32_LSECLK                0U
#endif

#define STM32_LSEDRV                (3U << 3U)

#if !defined(STM32_HSECLK)
#define STM32_HSECLK                8000000U
#endif

/*
 * MCU type as defined in the ST header.
 */
#define STM32F042x6

/*
 * IO pins assignments.
 */
#define GPIOA_RD_nSAMPLE            0U
#define GPIOA_RD_RES0               1U
#define GPIOA_RD_RES1               2U
#define GPIOA_RD_A0                 3U
#define GPIOA_RD_A1                 4U
#define GPIOA_RD_nLOT               5U
#define GPIOA_RD_nDOT               6U
#define GPIOA_PIN7                  7U
#define GPIOA_PIN8                  8U
#define GPIOA_UART_TX               9U
#define GPIOA_UART_RX               10U
#define GPIOA_CAN_RX                11U
#define GPIOA_CAN_TX                12U
#define GPIOA_SWDIO                 13U
#define GPIOA_SWCLK                 14U
#define GPIOA_RD_SPI_nCS            15U

#define GPIOB_PIN0                  0U
#define GPIOB_PIN1                  1U
//#define GPIOB_PIN2                  2U
#define GPIOB_RD_SPI_SCK            3U
#define GPIOB_RD_SPI_MISO           4U
#define GPIOB_RD_SPI_MOSI           5U
#define GPIOB_RD_nRESET             6U
#define GPIOB_PIN7                  7U
#define GPIOB_BOOT0                 8U

#define GPIOF_OSC_IN                0U
#define GPIOF_OSC_OUT               1U

/*
 * IO lines assignments.
 */
#define LINE_RD_nSAMPLE             PAL_LINE(GPIOA, GPIOA_RD_nSAMPLE)
#define LINE_RD_RES0                PAL_LINE(GPIOA, GPIOA_RD_RES0)
#define LINE_RD_RES1                PAL_LINE(GPIOA, GPIOA_RD_RES1)
#define LINE_RD_A0                  PAL_LINE(GPIOA, GPIOA_RD_A0)
#define LINE_RD_A1                  PAL_LINE(GPIOA, GPIOA_RD_A1)
#define LINE_RD_nLOT                PAL_LINE(GPIOA, GPIOA_RD_nLOT)
#define LINE_RD_nDOT                PAL_LINE(GPIOA, GPIOA_RD_nDOT)
#define LINE_RD_SPI_nCS             PAL_LINE(GPIOA, GPIOA_RD_SPI_nCS)

#define LINE_RD_nRESET              PAL_LINE(GPIOB, GPIOB_RD_nRESET)

/*===========================================================================*/
/* Driver pre-compile time settings.                                         */
/*===========================================================================*/

/*===========================================================================*/
/* Derived constants and error checks.                                       */
/*===========================================================================*/

/*===========================================================================*/
/* Driver data structures and types.                                         */
/*===========================================================================*/

/*===========================================================================*/
/* Driver macros.                                                            */
/*===========================================================================*/
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

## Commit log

2019-12-28 Update pcb/lib/agg-kicad ref.
2019-12-28 Initial commit of files.
    [scot-resolver.kicad_pcb, scot-resolver.sch]
2020-01-01 WIP PCB (starting layout)
    [scot-resolver-can-txrx.sch, scot-resolver-exciter.sch, scot-resolver-mcu.sch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]
2020-01-01 Add datasheets.
    [EVAL-CN0276-SDPZ-BOM-RevA.xlsx]
2020-01-05 PCB Progress, laying tracks.
    [scot-resolver-exciter.sch, scot-resolver-power.sch, scot-resolver-receiver.sch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]
2020-01-06 sym-lib-table: Use relative path for agg-kicad lib.
2020-02-17 WIP (nearly there!)
    [scot-resolver.kicad_pcb, scot-resolver.sch]
2020-02-19 Sent to fab (fab5)
    [scot-resolver-B_Cu.gbl, scot-resolver-B_Mask.gbs, scot-resolver-B_Paste.gbp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]
2020-02-19 Renaming of files.
    [scot-resolver-B_Cu.gbr, scot-resolver-B_Mask.gbr, scot-resolver-B_Paste.gbp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]
2020-03-03 pcb: Add labels and values to schematic.
    [scot-resolver-power.sch, scot-resolver.sch]
2020-03-03 Add BOM.
2020-03-05 pcb/BOM: Add mosuer parts list.
2020-03-06 pcb/BOM: Add warning of mistake (2nd can txrx ordered not a diode)
2020-03-29 pcb/agg-kicad: Update lib reference.
2020-04-01 Add STM32F0 ref manual to docs.
2020-04-02 Add crude python canbus view script.
2020-04-04 firmware: Fix git version in CAN sysinfo messages.
    [can_view.py, main.c]
2020-04-04 pcb/lib/agg-kicad: Change to https URL for Travis CI compatibility.
2020-04-04 firmware: Add CAN RX filter.
2020-04-06 firmware: Add reset of RD IC on _init() and on config parity error.
    [ad2s1210.c, board.h]
2020-04-10 pcb/: Re-render schematic pdf.
2020-04-10 firmware/ad2s1210c: Re-order RD start up sequence to fix reported faults.
    [ad2s1210.c]
2020-04-20 WIP PCB v2.
    [scot-resolver-can-txrx.sch, scot-resolver-mcu.sch, scot-resolver-power.sch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]
2020-04-25 pcb: V2 schematic updates (PCB still to do).
    [scot-resolver-B_Cu.gbr, scot-resolver-B_Mask.gbr, scot-resolver-B_Paste.gbr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]
2020-04-26 pcb: Add Receiver second stage calculations to schematic.
    [scot-resolver-receiver.sch]
2020-04-26 pcb: Add 10u to VREF, all 0402->0603
    [scot-resolver-can-txrx.sch, scot-resolver-exciter.sch, scot-resolver-mcu.sch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]
2020-04-26 pcb: Add analog testpoints.
    [scot-resolver.sch]
2020-04-26 pcb: WIP layout of v2.
    [scot-resolver.kicad_pcb]
2020-06-02 pcb: Progress on v2 layout.
    [scot-resolver-mcu.sch, scot-resolver.kicad_pcb, scot-resolver.sch]
2020-06-02 pcb: Clear up exciter ground rail (sch & pcb).
    [scot-resolver-exciter.sch, scot-resolver.kicad_pcb, scot-resolver.sch]
2020-06-03 pcb: Progress on layout.
    [scot-resolver.kicad_pcb]
2020-06-04 pcb: Finish v2 and send off for manufacture.
    [scot-resolver-B_Cu.gbr, scot-resolver-B_Mask.gbr, scot-resolver-B_Paste.gbr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]
2020-06-05 pcb: Add v2 BOM, fix some component values.
    [scot-resolver-exciter.sch, scot-resolver-mcu.sch, scot-resolver-power.sch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]
2020-06-05 pcb/BOM: Add quickpaste list.
2020-06-05 pcb/BOM: De-duplicate BOM lines.
2020-06-09 firmware/can.c: Use native 16b slots.
2020-06-22 pcb/BOM: Fixes (unfinished).
2020-07-25 firmware/: Load CAN address from STM32 config id. Add STM32 ID for existing board.
2020-08-09 pcb/BOM: Minor updates.
2020-08-15 pcb/BOM: Checked C8 footprint - is 1210.
2020-08-16 firmware/flash: Add Device ID readout. (`./flash -I`)
2020-08-16 firmware/config.c: Add STM32 ID for new Azimuth resolver board (June 2020)
2020-08-16 README: Add June 2020 PCB errata.
2020-08-18 README: Expand PCB errata.
2020-08-29 Add more PCB errata notes.
2020-08-29 firmware/flash: Add C-friendly STM32 ID output.
2020-08-29 firmware/config.c: Swap EL resolver board for June2020 board.
